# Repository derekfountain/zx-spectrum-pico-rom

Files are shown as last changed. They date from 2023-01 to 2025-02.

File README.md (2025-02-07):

# zx-spectrum-pico-rom

## A Pico-based switchable ROM interface for the ZX Spectrum

This is a ROM interface board for the ZX Spectrum. It presents a new,
selectable ROM image for the machine, replacing the 1982 BASIC one
found in the IC on the Spectrum's PCB.

There are lots of these around, all based on ROM and EEPROM chips. My
design is based on a Raspberry Pi Pico microcontroller programmed to
emulate a ROM chip.

The main advantage of doing it this way is that the Pico has enough
memory for several ROM images, and enough flash for as many ROMs as
anyone would likely ever want. A button allows the loaded ROMs to be
cycled.

It works like this (click through for YouTube video):

IMAGE ALT TEXT (http://www.youtube.com/watch?v=0Ot5mol2f5A "ZX ROM Interface")

https://youtube.com/shorts/0Ot5mol2f5A?feature=share

Update Dec'24: I used this Pico ROM project as the basis for a bit
of experimentation with the Z80's non maskable interrupt (NMI) on 
the Spectrum. Updated software and description are [here](https://github.com/derekfountain/zx-spectrum-pico-rom/tree/main/firmware_nmi).
If you're after a simpler version of the Pico code to do a simple
ROM emulation task, that's probably the version you want.

Update Feb'25: I further used this Pico ROM project as the basis for adding a carefully timed non maskable interrupt (NMI) which fires each frame at the point the Spectrum is about to draw the lower border. Not sure how much value there is there, but if anyone's interested the subproject is [here](https://github.com/derekfountain/zx-spectrum-pico-rom/tree/main/firmware_nmi_lower_border).

## Design

The Z80's address and data bus lines are connected to the Pico's
GPIOs.  GPIOs are limited on the Pico (there's only 26), so only 14 of
the 16 address lines are connected. A bit of external logic handles the
top two. The software on the Pico sits spinning, watching for that logic
to indicate that A14, A15 and /MREQ are all zero, that being the indication
of a ZX Spectrum ROM memory access by the Z80. When that condition is
met the address the Z80 is requesting (in the range 0x0000 to 0x3FFF)
is found from the GPIOs connected to the address bus, and the value from
that offset in the currently enabled ROM image is fetched. The 8 bits of
that value are placed on the 8 GPIOs connected as outputs to the Z80's
data bus.

## Hardware design

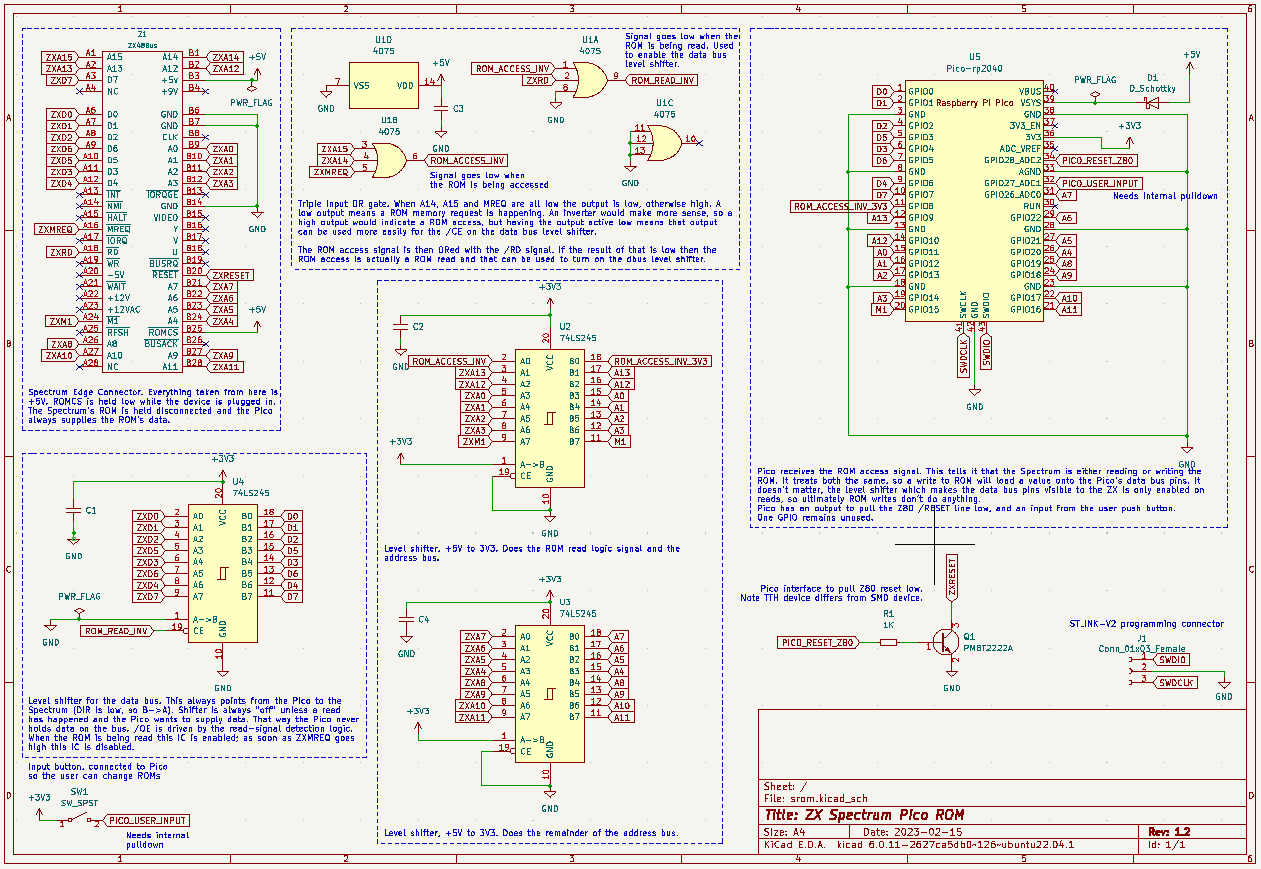
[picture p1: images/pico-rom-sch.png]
Pico ROM Schematic


The Spectrum is +5V, the Pico is 3V3, so every bus or signal pin needs
level shifting, down on the way into the Pico, up on the way out.

GPIO count is also pretty tight, which is why the external logic is
required. It's a simple 3-input OR gate which ORs A14, A15 and
/MREQ. The output of that gate is fed into the Pico, saving 2 GPIOs.

It's important that the device doesn't assert an output value onto the
Z80's data bus until it needs to. This is controlled by hardware. The
data bus level shifter is set permanently to the Pico->ZX direction,
but is left off (via its chip-enable line) until the ROM is being
read. The /CE line is pulled low by the output of the 3-way OR gate,
so when the Z80 is reading from ROM the level shifter is turned on and
the value on the data bus is connected to the Z80. As soon as the
/MREQ line goes high again the OR result goes true and the level shifter
is turned off again.

The Pico needs the ability to reset the Z80, which gets very unhappy if
the ROM program it's running is suddenly changed from underneath it. The
Z80's /RESET line is connected to a GPIO via a transistor; the line is
pulled low via Pico software when the Pico changes the ROM image in order
to reset the Z80.

There's a single user input button connected to the one remaining GPIO
on the Pico. In the current software this cycles the ROM to the next one
in the (compiled in) sequence. The Pico's ADC is available so more buttons
and a better user interface could be constructed using a resistor ladder.

The Z80's /M1 line is connected to a Pico GPIO input. This isn't required
for the typical use case, but it makes the device a useful test bed for
running the ZX Interface One ROM - see below.

### Caveat

Feb'25: I was playing around with one of these interfaces, and found myself
wanting to re-enable the Spectrum's ROM with the interface still plugged in.
(I needed the Pico for something, but with the Spectrum's own ROM.) So I
cut the /ROMCS track on the back of the interface, and then spent some time
trying to figure out why the Spectrum wasn't working.

Eventually it dawned on me: when I cut the track the Spectrum's ROM IC
was re-enabled, and it started to drive the data bus. But the U4 level
shifter was still working on the interface, which meant that was also driving
the data bus. That's a bad thing, the two ICs were both trying to be outputs
and were driving each other's data lines. The Z80 was getting garbage on the
data bus, and I think I was rather lucky nothing got damaged. I removed the
level shifter to complete my experimentation.

So, um, don't do that. :)

### Construction

The gerbers archive for upload, for example, JLCPCB, is
srom/fab1.2/fab1.2.zip. It's a simple 2 layer board.

Note: As of this writing I've not actually had one of these made. I
hand-modified my v1.1 board with the errata from v1.1. The v1.2 design
has had those modifications added so I'd expect it to work exactly the
same as my modified v1.1 board. But I haven't tried it yet. The switch,
in particular, might yet require another tweak depending on what
piece of hardware is chosen. I used a 6mm x 6mm right angle switch.

There's nothing complicated about the soldering. Do the big ICs first
and the Pico sockets, if you use them, last.

## Software Design

The software which runs on the Pico is built on a simple loop which
does this:

 * spin, waiting for the ROM-being-accessed signal to come in
 * read the 14 bits of the address bus from the GPIOs
 * convert that bit pattern into an offset
 * find the value of the byte at that offset into the currently
   used ROM image
 * apply the 8 bits of that byte value to the 8 output GPIOs connected
   to the Z80's data bus
 * go back to the top

The glaring issue here is speed. Pg8 of the Z80 manual says that the
timing for M1, the instruction fetch, is most time critical. The data
is sampled off the bus one and a half clocks after /MREQ goes low. On
the Spectrum's 3.5MHz Z80 that's 4.28571428571e-07 seconds, so about
430ns. Despite several efforts at optimisation I've been unable to get
the Pico to reliably return the data value inside that time frame. Much
to my frustration, v1.2 of the software still requires an overclock from
133MHz to 140MHz.

The Z80 starts up faster than the Pico which requires half a second or
so to get going. This means the Z80 is asking for ROM instructions 
before the Pico is ready to provide them. The Pico resets the Z80 as
soon as it, the Pico, is ready to go. That's why there's a colourful
display of randomness for a moment at startup.

## ROM Images

The device is permanently enabled; the original ROM chip in the
Spectrum is disabled while the interface is attached.

The Pico software contains the ROM images it's compiled with, the
first of which would typically be the original ZX ROM from 1982. I've
added a diagnostics ROM and the Gosh Wonderful ROM since they are free
to redistribute. Games ROMs are not included in the source release but
they can be added fairly easily. A Linux command like:

 xxd -i spaceraiders.rom

will convert a ROM image into 'C' array data which can be dropped into
roms.h.

### Switcher ROM

Some of the ROMs look superficially similar, like the original 1982
ROM and the Gosh Wonderful ROM. It got confusing trying to work out
what was running. I wanted a row of LEDs across the top of the device
to act as an indicator of which ROM was in use, but I didn't have any
GPIOs to implement it with. So I added an extra ROM image I called the
"switcher" ROM.

This program is written in 'C' and compiled with Z88DK. The source is
in the firmware/switcher directory. It presents a banner saying what ROM
is coming up next, then sits indefinitely buzzing the Spectrum's border.

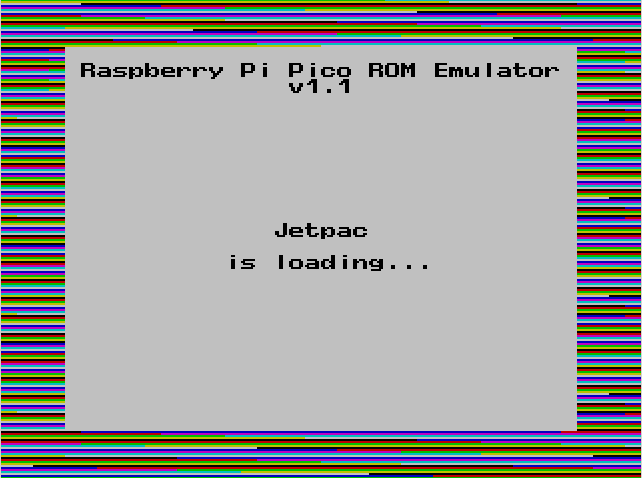
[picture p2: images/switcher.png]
Switcher ROM (under emulation)


When the user input button is pressed, the Pico software selects this
switcher ROM and resets the Z80 to start it running. The banner appears
on the Spectrum screen. About a second later an alarm goes off in the
Pico, the handler for which selects the next ROM in sequence and resets
the Z80 again. Thus the switcher ROM appears as a banner on the Spectrum
screen between each ROM switch.

## ZX Interface One

This device can also switch in and out the ZX Interface One's ROM. This
is an 8K ROM which, in the actual IF1, is paged in by hardware on 3 magic
address accesses: it's paged in when the Z80 requests an instruction from
addresses 0x0008 and 0x1708, and paged out again when the Z80 requests an
instruction from address 0x0700. It's early days with this idea, but that
boils down to this code:

    if( (rom_address == 0x0008) || (rom_address == 0x1708) )
    {
      rom_image_ptr = __ROMs_if1_rom;
    }
    else if( rom_address == 0x0700 )
    {
      rom_image_ptr = __ROMs_48_original_rom;
    }

This needs the /M1 input merged into the logic, but that's the
idea. The joys of programmable devices like the Pico, as opposed to
hardware. :)

There's a macro in the firmware source to switch in an early IF1 paging
version of the code. It seems unreliable, but I won't be persuing this
any further with this project.

Note: the v1.1 board doesn't have the /M1 signal connected. The v1.2
board has it connected into GPIO15. The software doesn't have the /M1
signal taken into account as yet.

## Bill of Materials

You will need:

3x [74LVC245 Bus transceiver](https://www.mouser.co.uk/ProductDetail/595-SN74LVC245ANSR)
Bus transceiver, used as a level shifter
<br>
1x [3216 SMD Diode](https://www.mouser.co.uk/ProductDetail/581-SD1206S040S2R0)
Schottky Diode for Pico input protection
<br>
1x [4075 OR gate](https://www.mouser.co.uk/ProductDetail/595-SN74HCS4075DR)
3-way 3-input OR gate
<br>
4x [3216 SMD 0.1uF capacitor](https://www.mouser.co.uk/ProductDetail/581-12065C104KAT4A)
Decoupling capacitor
<br>
1x [PMBT2222A SMD Transistor](https://www.mouser.co.uk/ProductDetail/771-PMBT2222A-T-R)
NPN Transistor for /RESET
<br>
1x [3216 SMD 1K Resistor](https://www.mouser.co.uk/ProductDetail/603-RT1206FRE071KL)
1K Resistor for /RESET

Also:

1x Raspberry Pi Pico with pins and sockets if you want them
<br>
1x ZX Spectrum Edge Connector socket
<br>
1x SPST switch any single pole, single throw switch to use as an input button. The footprint
on the board matches one I happen to have had, assume you'll add it on flying leads.

## Licence

Distributed as free software and hardware design under the GPL. The ROM
images have their own licences, see the ROMs/ directory.

Derek Fountain
February 2023

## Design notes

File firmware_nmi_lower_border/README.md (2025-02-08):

# zx-spectrum-lower-border-nmi

## A Pico-based NMI at the lower border point for the ZX Spectrum

I previously did some work looking at the use of the Z80's Non Maskable Interrupt with the ZX Spectrum. That work is [here](https://github.com/derekfountain/zx-spectrum-pico-rom/tree/main/firmware_nmi).

This sub-project builds on that idea, using RP2040 PIOs to generate a non maskable interrupt at a precisely defined point in the frame generation.

### Background

As most Spectrum aficionados know, the best time to redraw the screen and update sprites is when the border is being drawn. That way the screen won't flicker. Only, the Spectrum's hardware only has a single timer, which is the 50Hz signal the ULA emits when the video frame is about to be generated - i.e. when the raster beam is at the very top of the screen.

What might be useful, I thought, is a different interrupt which fires just as the ULA finishes drawing the screen data, which is the point it's just about to start drawing the lower border. Synching a program to that signal would give quite a bit more time to update the screen - the time needed to draw the lower border, plus the time needed to draw the top border.

This idea would require very precise timing, and the only reference point is the ULA's INT signal. The RP2040 on the Pico has its PIOs, which are very good at very precise signal handling. This project uses the PIOs to generate a NMI signal exactly as the ULA is about to start drawing the lower border.

### The Video Frame

A frame of the Spectrum's video signal looks like this on an oscilloscope (yellow trace shows the interrupt (INT) signal):

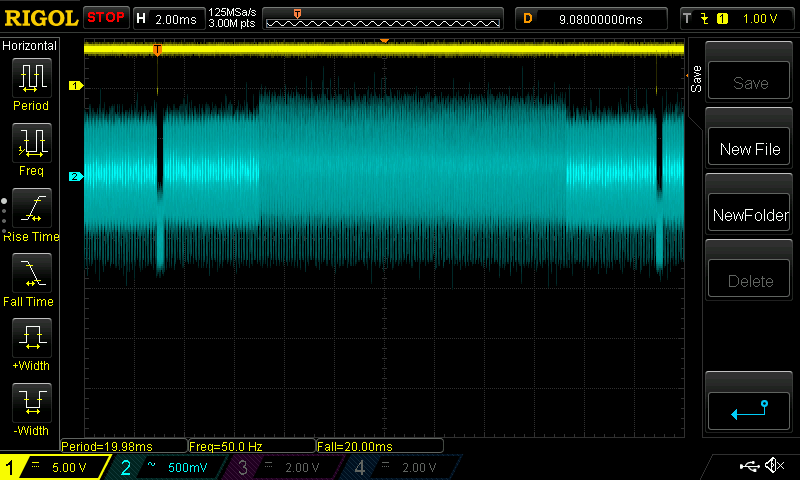
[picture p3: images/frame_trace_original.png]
Frame trace


There are 3 clearly defined areas of this signal, as annotated here:

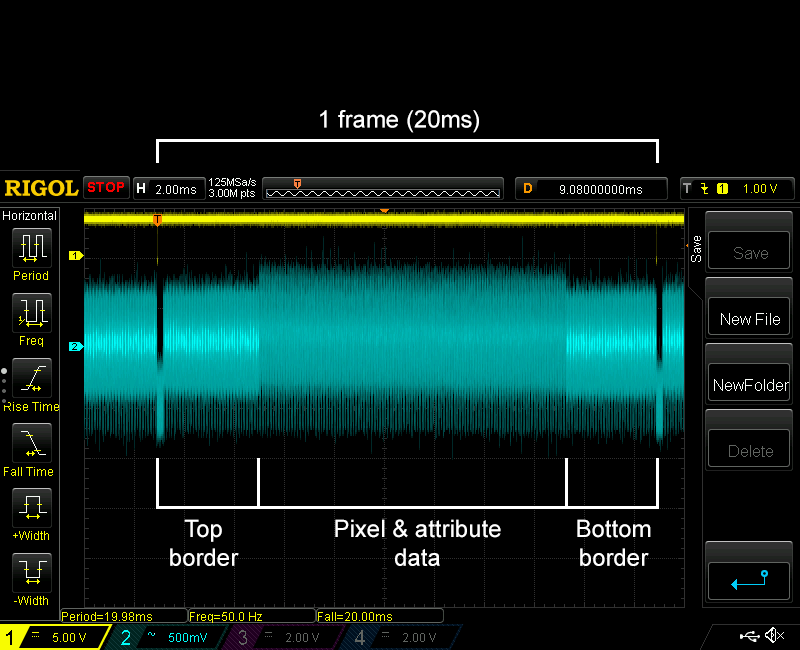
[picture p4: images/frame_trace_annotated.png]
Frame trace annotated


(Zooming in to the oscilloscpe trace shows the 192 lines of pixel data in that central block.)

The goal of this project is to generate a NMI signal at the exact point the bottom border is about to be drawn, as shown by the purple line here:

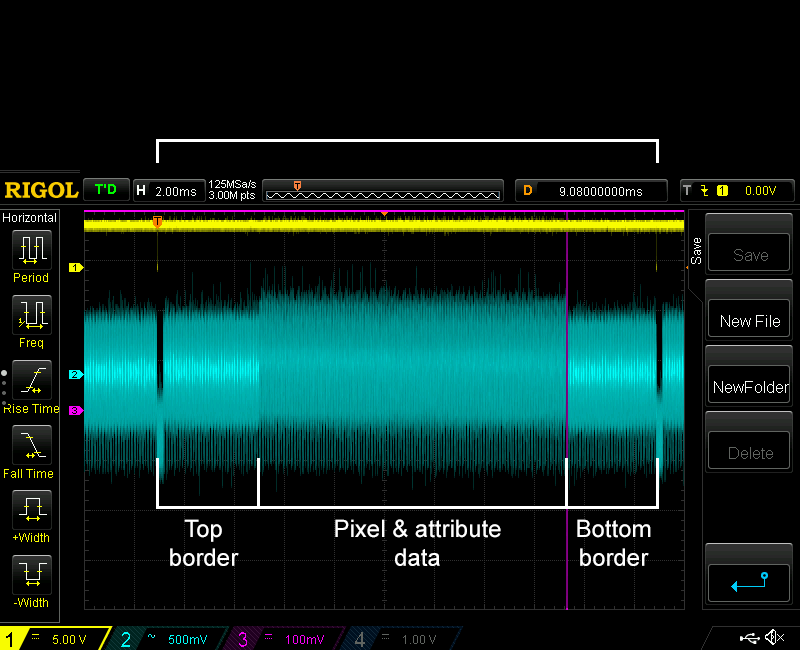
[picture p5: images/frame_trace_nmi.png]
Frame trace NMI


### The Result

The project works as designed, using a PIO-derived signal on each frame of video data (i.e. at 50Hz) to generate a non maskable interrupt on the Z80.

Look carefully at this photo of a Spectrum screen and you'll notice a thin, fractional, magenta line being drawn just underneath the lowest line of text:

Magenta line

That line is being drawn in the lower border by a NMI handler routine which just changes the border colour to magenta, then changes it back to white. The thin line thus created in the border is permanent, it just sits there. That includes when the Spectrum is running machine code programs with the interrupts disabled - it's a non maskable interrupt which is putting that line there.

This isn't a particularly useful example but it shows the NMI is being generated at exactly the right time, and the Z80 is running a simple handler for it.

## How it works

There are several pieces to this.

### ROM Emulator (modified)

The first is the piece of hardware which connects the Pico to the ZX Spectrum. For that I've used my ROM emulator project, which is the parent project of this one.

I modified it slightly, attaching the Z80's /INT signal to the Pico's GPIO 15. Ideally it would come in via a level shifter (5V to 3V3) but I didn't have a spare level shifter port. The RP2040 can handle a 5V input like this, so it's OK. The other modification is the NMI output signal from the RP2040 to the edge connector, and hence on to the Z80. I reused the original switch GPIO for this, that not being needed on this project.

So, just the two patch wires needed to modify the hardware.

### A PIO Program

The Spectrum's video takes exactly 20ms to draw, and hence runs at 50 frames per second. It's [312 scan lines high](https://worldofspectrum.org/faq/reference/48kreference.htm): 64 scans for the top border, 192 scans for the pixel data, then 56 scans for the lower border. Each scan line takes 224 T-states of the 3.5MHz Z80 to draw. Long story short, the NMI is required exactly 64+192 scan lines after the /INT signal is received. That's 64us, after which the /NMI signal to the Z80 needs to be pulled low.

The PIO program in this project does exactly that: wait for the /INT signal, then wait 64us, then pull the output GPIO low. The PIO program is this:

```
	 set pins, 1
 .wrap_target
	 wait 0 pin 0 [31]

     set x, 30 [31]
 first_lines:                                           
	 nop [31]
	 jmp x--, first_lines [31]

	 set pins, 0
	 set pins, 1
 .wrap
```

Start with the NMI output high, then wait for the /INT. There's a loop full of NOPs, then it toggles the output pin low and high. The numbers in square brackets are the delays on the PIO instructions, selected to set the timing exactly right. The lengthy comments in the PIO source code detail how the delays were worked out. I found it easier to reduce the clock speed of the PIO state machine from the 125MHz it normally runs at down to 125KHz. That made the correct delays much easier to generate.

### Spectrum ROM (modified)

When the Z80 receives the /NMI signal it jumps to location 0066h, which is in the Spectrum's ROM. The routine at that location isn't used, probably because it's buggy. But because I used my ROM emulator as the basis for this project, I'm in control of what's in the ROM, and I can fix the bug. In fact, what I actually did during development was put a single RETN instruction at location 0066h, which made testing predictable.

For the final version, which draws that magenta line, I put this in the ROM:

```
push af
ld a, 3
out (254),a
out (254),a
ld a, 7
out (254), a
pop af
retn
```

The original handler is 14 bytes, and that is 14 bytes, including the repeated 'out' instruction to set the border magenta. I had those 2 bytes spare, so I repeated the border colour change to make the magenta line a bit longer. Come to think of it, 2 NOPs would have done the job.

## Any Real Application?

This was mostly an exercise is trying to do something with non maskable interrupts on the Spectrum and PIOs on the RP2040. But it might have a real world application.

The Spectrum is a games machine, and I have in the past pondered hardware which would make for better games: smoother sprites, larger scrolled areas, etc. This would be a starting point, giving the games programmer a more reliable alternative to the [floating bus trick](http://sky.relative-path.com/zx/floating_bus.html), which aims to do the same thing from software.

In practise, um, no, not really, but if anyone has a use for it, feel free. :)

[Derek Fountain](https://www.derekfountain.org/zxspectrum.php), February 2025

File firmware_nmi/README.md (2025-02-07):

# zx-spectrum-nmi

## A Pico-based NMI testbed for the ZX Spectrum

I wanted to do some experimentation with the Z80's non maskable interrupt.
The Spectrum's NMI handler is buggy in the [Sinclair ROM](https://skoolkid.github.io/rom/dec/asm/102.html)
so it's never been possible to play with it, but with the ROM running from
an interface it's trivial to patch the problem in the interface's ROM image.

### Fixing the bug

The bug is simply a JR NZ instruction where a JR Z instruction was needed.
So my [ROM image](https://github.com/derekfountain/zx-spectrum-pico-rom/blob/9dbc9985f971bbe39fc13d4d96b5a7a9dd7bb2ee/firmware_nmi/roms.h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) needs a 0x28 in place of the 0x20, like this:

> 0xb5, 0x28, 0x01, 0xe9, 0xe1, 0xf1, 0xed, 0x45, 0x2a, 0x5d, 0x5c, 0x23,   /* <-- Fix at second byte here */

Simple.

### Modifying the interface

There's only one GPIO free on the board design, which is GPIO15. So I wired
that from the Pico to the NMI pin on the Spectrum's edge connector. This
gives the Pico the ability to trigger the Z80's NMI.

### Updating the interface code

The code running in the Pico needed a bit of tweaking. What it really needed
was simplfying, since for this project I didn't need any of the ROM switching
code I had in there.

The main issue I found was that the original code was designed to reset the
Spectrum after the switch is pressed. This project needs the Spectrum to keep
running after the switch is pressed, and it didn't. So that got restructured
a bit, then I found I had a timing problem.

The ROM emulation doesn't have much time to spare. It already had a slight
overclock on the RP2040 to make it reliable, and adding more code didn't help.
The code handles the Z80's read, then sits spinning while the Z80 finishes
what it's doing. Once that's complete and the read operation is done, there's
not much time until the next one starts.

It turned out the main culprit was the access to the realtime clock which was
used for the switch debounce logic. Reading that clock takes 1.5uS which is
quite a long time when you're trying to get stuff done between Z80 instructions.
So I changed the debounce algorithm and went to a 200MHz overclock. Not ideal,
but it works well enough.

## The Spectrum end

With the Spectrum's ROM bug fixed, the operation of the NMI is as follows.

You put an NMI handler in memory somewhere, then set the NMIADD (at 23728)
system variable to point to it. When the NMI line is pulled low the Z80 will
jump to address 0x0066 where the (fixed) handler will save AF and HL on the
stack, then jump to the address NMIADD points to.

So I put this little program in RAM at 0x8000:

```
ld a,3
out (254),a
ld a,7
out (254),a
pop hl
pop af
retn
```

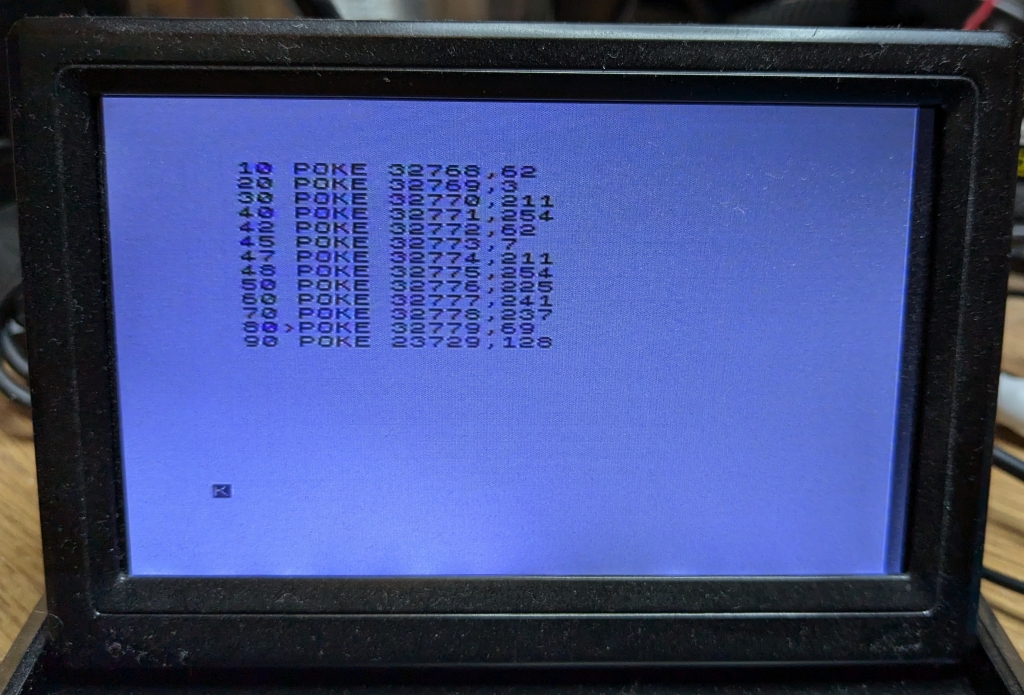
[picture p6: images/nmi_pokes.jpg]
POKEs to set up the NMI


So set the border to colour 3 (magenta) then set it back to colour 7 (white),
then restore the registers and return from the NMI. POKEing 23729 with 0x80
sets up NMIADD and ... it works! When I press the button on the interface
there's a quick flicker of magenta in the border.

I was quite pleased with getting that to work, but I can't really think what
to do with it.

Update Feb'25: I did a bit more with this NMI idea, using RP240 PIO to sync it to the 50Hz interrupt. Details [here](https://github.com/derekfountain/zx-spectrum-pico-rom/tree/main/firmware_nmi_lower_border).

[Derek Fountain](https://www.derekfountain.org/zxspectrum.php), December 2024

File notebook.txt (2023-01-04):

Project to get a Pico emulating a ROM on the Spectrum
=====================================================

Timing
======

Timing is based on a Z80 read, the ULA isn't involved. Pg8 of the Z80 manual says
that the timing for M1, the instruction fetch, is most time critical. The data is
sampled off the bus one and a half clocks after MREQ goes low. On the 3.5MHz Z80
that's 4.28571428571e-07 seconds. That's about 430ns.

For non-M1 accesses, timing is slower:

"Figure 6 shows the timing of memory read or write cycles other than an op code fetch
cycle. These cycles are generally three clock periods long unless wait states are requested
by memory through the WAIT signal."

The Interface2 doesn't use a WAIT signal, so the ROM needs to respond with data within the
expected timeframe, which is 3 clocks which is 8.57142857143e-07. That's 850ns.

430ns is therefore the requirement, and the Pico can do that quite easily.

This should be provable on a breadboard.

Signals
=======

The Interface 2 circuit is here:

http://www.fruitcake.plus.com/Sinclair/Interface2/Interface/Interface2_Circuitry.htm

It's got 16 address lines (inputs), 8 data lines (outputs) and the MREQ line (input).
It requires A14, A15 and MREQ to all go low to indicate a ROM (lower 16K) access.

The ROMCS (ROM Chip Select) line is permanently held high so the ZX ROM is permanently
disabled while the interface is plugged in.

The data bus GPIOs need to be left as inputs until a value is to be placed on them.
This is to allow other devices to use the Z80's data bus.

Pico Design
===========

Pico is GPIO constrained. It requires A0 to A15 as inputs, and D0 to D7 as outputs.
MREQ and RD will show that it's a memory access.

So I need 2 control lines, 16 address lines and 8 data lines. That's 26 lines. Bit
tight, but possible.

If /MREQ is low it's a memory access; if A14 and A15 are also low it's a memory
access of the lower 16K, the ROM. If the /RD line is also low it's a read of
the ROM, which is what I'm after. That's a 4 way OR, or maybe a 3 way OR plus
another 2 way OR. If I do this in discrete logic I'll free up some GPIOs.

I don't really want to have to have the Pico switching the output level shifter on.
It can do so, but it's another complication. So the design is to take the output
of the above described logic and use that to turn the level shifter on. When the
Z80 indicates it's doing a read from ROM, the active-low signal confirming that
can be used a /CE for the output level shifter.

I need to watch for a write to the ROM. In theory nothing will do that. I can use
it as a way for the Spectrum to communicate with the Pico. If I pass the output
of the discrete logic into the Pico it will be able to tell when ROM is being
accessed. If I pass in the /WR signal as well it will be able to tell if it's
being written to. This will allow POKE 0,?? to switch ROM. But that will crash
the Z80 so LD 0,???; JP 0 would be required. Unless the Pico can reset the Z80?
I don't think I have another level shifter port. Oh, maybe add a reset button
which yanks the RESET line, then the POKE and a manual press would do it?

Extra Ideas
===========

Probably need a timer circuit on /RESET to hold the Spectrum in reset until the
Pico has booted.

Need a way to get the Pico back to ROM0 (the Spectrum ROM). A power cycle will
do it, but a reset button might be useful.

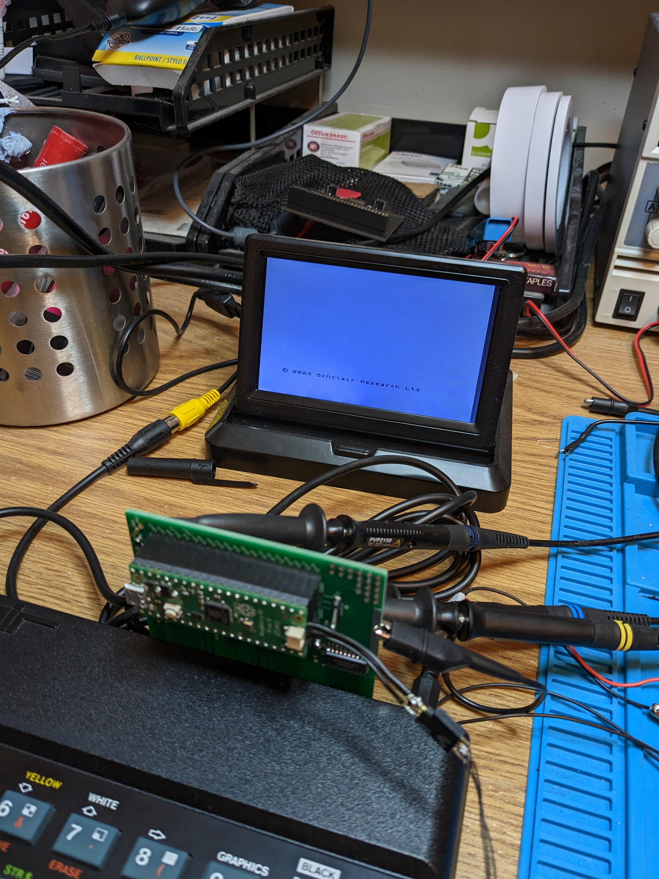
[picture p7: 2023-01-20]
srom/Images/first_working_version.jpg

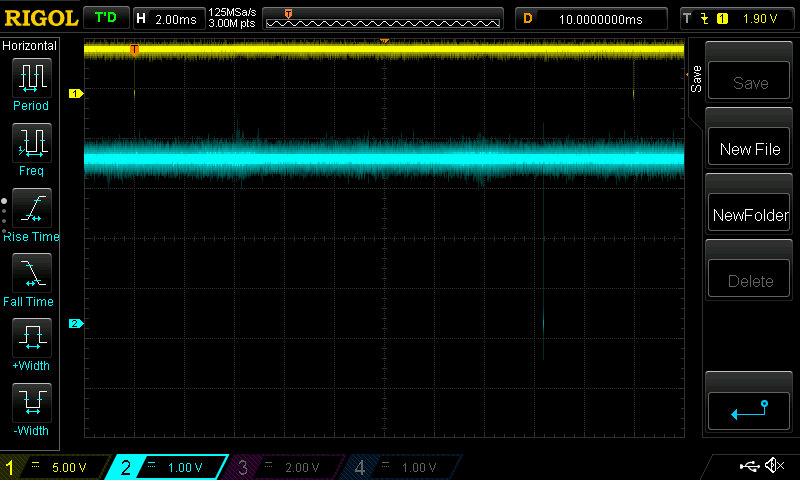
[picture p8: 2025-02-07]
images/nmi_from_int_pio.png

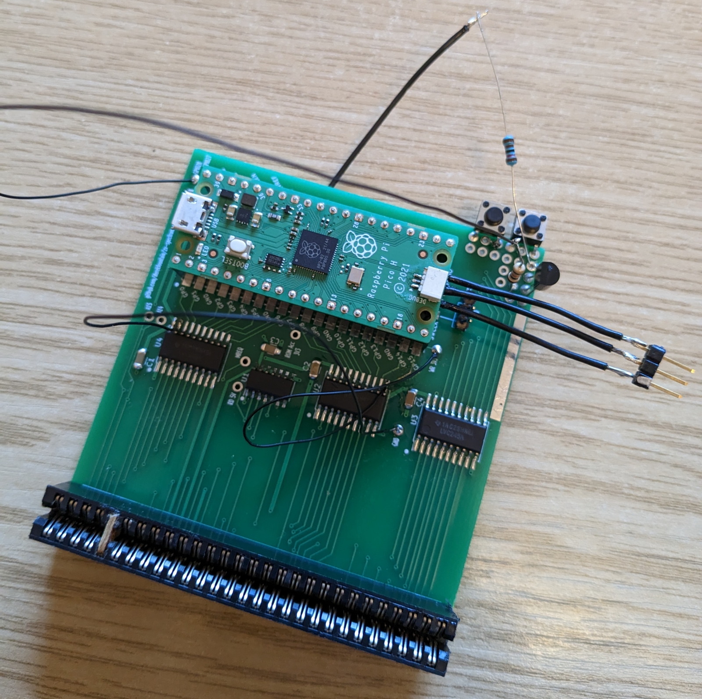
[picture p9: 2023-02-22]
images/first_version.jpg

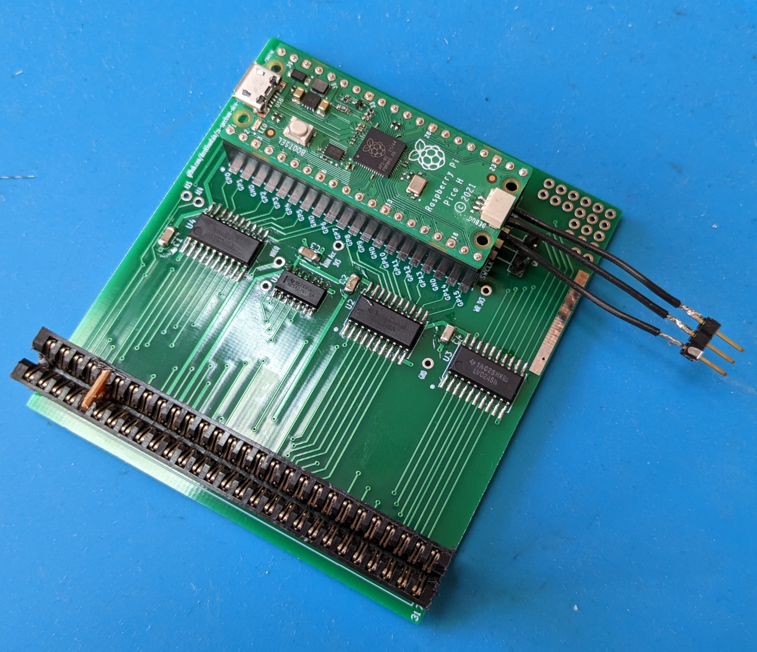
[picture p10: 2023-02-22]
images/first_built.jpg

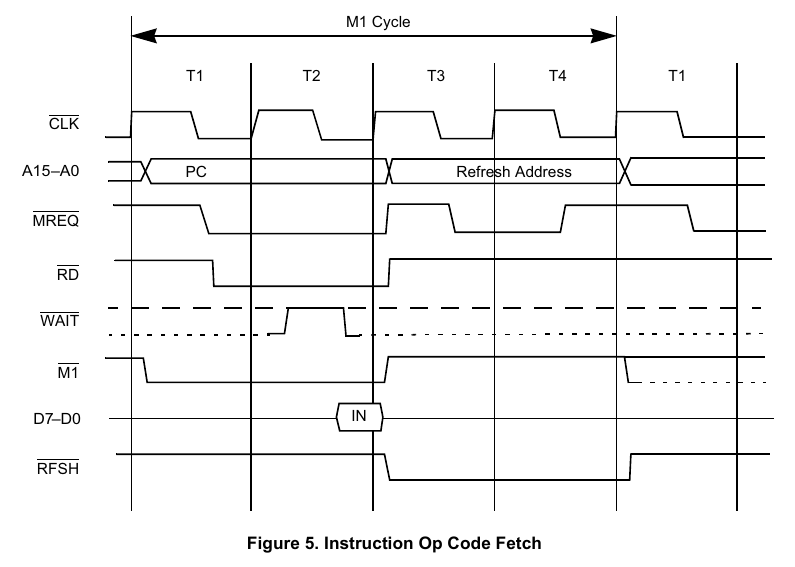
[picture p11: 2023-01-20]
srom/Images/mreq_timing_z80_datasheet.png

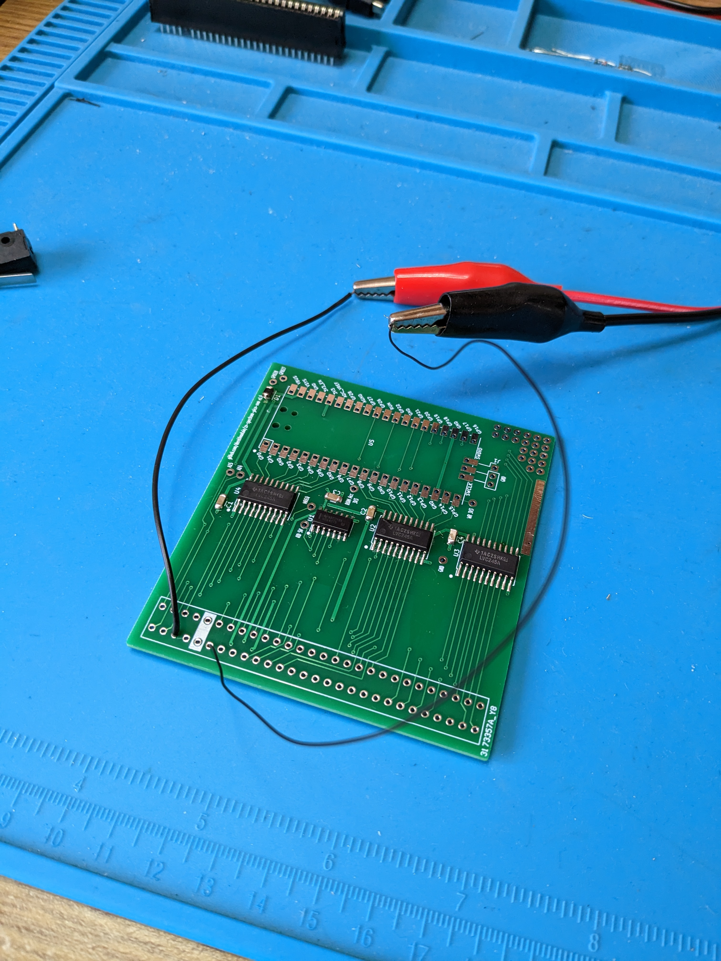
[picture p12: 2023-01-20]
srom/Images/initial_board.jpg

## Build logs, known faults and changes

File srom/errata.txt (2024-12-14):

1.0
===

The footprint for the SN74LVC245ANSR is wrong. The data sheet says 

SOIC (20) 12.80 mm × 7.50 mm

so I used the SOIC-20W_7.5x12.8mm_P1.27mm one. But there's a
discrepancy; the footprint is 7.5mm across the body of the device,
the datasheet says that distance is across the pins. The body of
the device is 5.00mm to 5.6mm according to the datasheet (which
it is). There isn't a non-wide version of that footprint in the
KiCAD libs. The one to use appears to be the SO-20_5.3x12.6mm_P1.27mm
one.

The footprint for the Pico's schottky diode is wrong. I copied AM's
circuit where he's used a SOD323 footprint. The diodes I bought are
3216 sized, and so too big. Increase footprint size.

I don't need the /WR line at the Pico. The level shifter for the
data bus is permanently in the Pico->ZX direction, so I can't
pick up a written value from the data bus. That level shifter is
turned on/off by hardware so there's no issue with the device
responding to a write-to-ROM in the same way as it responds to
a read-from-ROM. Delete the /WR connection and reclaim the GPIO
on the Pico.

It needs access to the Z80's /RESET line. It's a pain having to
use the switch on the Spectrum for something that the board can
do itself. This is also needed to start at address 0 when a new
ROM gets switched in. Pico needs a GPIO set to output which it
can use to bring the Z80's /RESET line low. I can use the GPIO
freed by the now unneeded /WR connection.

It needs a user input button. Writing to the ROM to reboot doesn't
seem practical. Pressing the button can advance to the next ROM in
the build. I think a brief press will select the next ROM and reset
the Z80, a long press can reboot the Pico itself.

In order for the Interface One ROM to page at the correct time I
need the Z80's /M1 signal. It's sort of a side point for the
purpose of this device, but will be useful for testing as I start
the IF1 project. I have a spare level shift and GPIO on the Pico.

I need +5V and 3V3 test points.

v1.1
====

The footprint for the right angle 6x6mm switch is wrong.
Button_Switch_THT:SW_Tactile_SKHH_Angled looks like a better option.
Fixed for v1.2.

The NPN2222 SMD transistor has a different pinout to the TTH hole I
used for prototyping. I created a new symbol with correct footprint
for v1.2.

The Pico receives a signal called ROM_ACCESS_INV, which is A14, A15
and /MREQ ORed together. Unfortunately that logic allows memory
refreshes through - see the Instruction Fetch section of the Z80
manual. This made sense when the Pico had the /RD signal, but since
that's now gone the Pico can't tell a read, write or refresh.
That's bad for the Interface One paging mechanism which
must only page with a memory read; a memory refresh of 0x0008 happens
at Z80 startup. The solution appears to be to put the ROM_READ_INV
signal through the level shifter and into the Pico instead of
ROM_ACCESS_INV, but I haven't done it yet. Needs thinking through.
For the IF1-demo use case /M1 can be used instead. /M1 goes high
for the refresh part of the read so the Pico can see the page
isn't required at that point. But see next point.

The 1.1 boards were fabricated with the Pico's GP15 not connected to
anything. It was /WR, which I disconnected. I intended to connect
/M1 but didn't actually do so. If this board is to run the IF1 ROM
switching reliably the /M1 signal will have to be put through the
level shifter and into the Pico. PCB has been updated with this
change for v1.2.

v1.2
====

The switch (SW1) casing isn't connected to ground. This makes it
susceptible to ESD: when I touch the switch's metal casing the
Spectrum sometimes crashes or reset. I think the issue is capacitive
coupling. Static from my fingertip goes through the capacitor formed
by the switch casing on one side and the Pico/ZX circuit on the
other, and the voltage ends up somewhere it shouldn't, like the Z80.
I soldered a wire from the switch case to a ground point and that
solved the issue.
Fixed for v1.3. I set the switch anchor points to GND net.

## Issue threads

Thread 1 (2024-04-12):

suggestion to retarget tje board

aldolo69, 2024-04-12:
hi. don't know how to write to you in another way.
in your opinion is possible to build a .z80 loader? for the porpuse maybe only 512bytes of the initial rom could be enough so you can freeup some pins for the sd card and buttons. you can makup the rom in chunks of LD command to fill the RAM and then release the z80 and the original ROM. i'm too lazy to start such a project now... seems doable.

derekfountain, 2024-04-14:
I think the approach could be made to work with enough effort. The issue, as ever with the Pico, is the number of GPIOs available.

If you re-purposed the GPIO which currently connects the /M1 line (as part of the IF1 experimentation I was doing), you could emulate a 1024b ROM with 4 GPIOs free. Those GPIOs could drive an SD card reader (MISI, MISO, CLK and SLAVE_ENABLE), the contents of which could be moved into Spectrum RAM in chunks as you suggest.

Hmmm, but then when your game is loaded and started you wouldn't have the original ROM in place, and that code is used by lots of games. So you'd need the ability to turn the device off which you could do by driving /ROMCS, but that would need another GPIO. You could re-purpose another address line and go down to a 512b ROM, which would probably still be enough for the Z80 program. So I think that bit would work. You wouldn't have any free GPIOs for user interface buttons though.

To be honest, if I were going to design such a project, I'm not sure I'd start with this one!

derekfountain, 2024-12-15:
Nothing further planned on this.

Closed 2024-12-15.

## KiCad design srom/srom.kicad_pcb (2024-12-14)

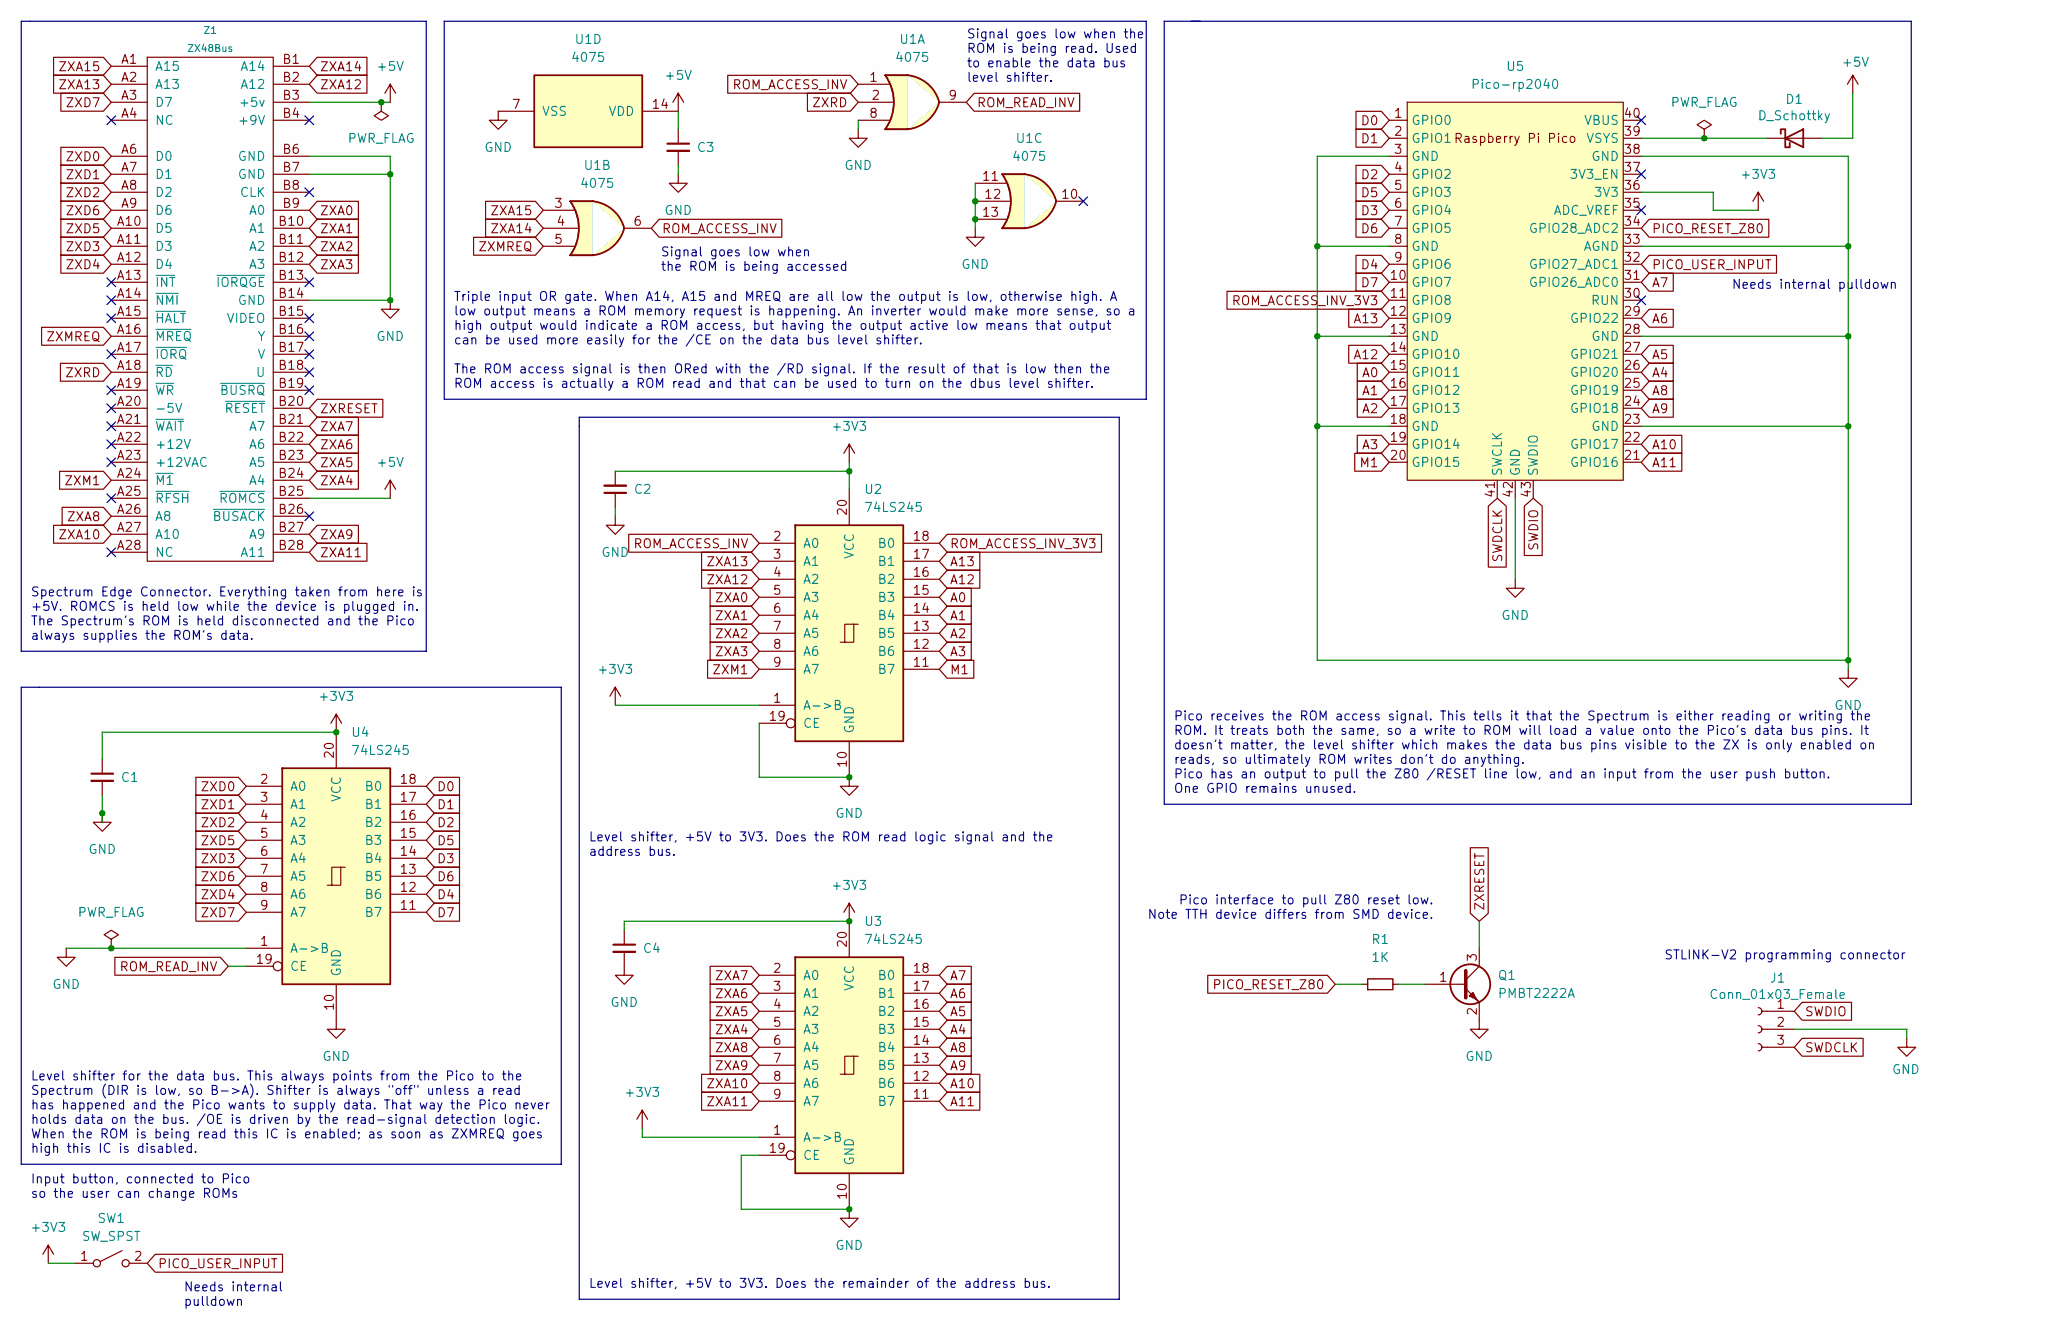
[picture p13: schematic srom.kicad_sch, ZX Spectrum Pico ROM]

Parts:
C1, C2, C3, C4: C_Small; C_1206_3216Metric
D1: D_Schottky; D_1206_3216Metric_Pad1.42x1.75mm_HandSolder
J1: Conn_01x03_Female; PinHeader_1x03_P2.54mm_Vertical
Q1: PMBT2222A; TSOT-23_HandSoldering
R1: 1K; R_1206_3216Metric_Pad1.30x1.75mm_HandSolder
SW1: SW_SPST; SW_Tactile_SKHH_Angled
U1: 4075; SOIC-14_3.9x8.7mm_P1.27mm
U2, U3, U4: 74LS245; SO-20_5.3x12.6mm_P1.27mm
U5: Pico-rp2040; RPi_Pico_SMD_TH
Z1: ZX48Bus; ZX_Bus_Pin_Header

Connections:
+3V3: C1.1, C2.2, C4.1, SW1.1 (A), U2.1 (A->B), U2.20 (VCC), U3.1 (A->B), U3.20 (VCC), U4.20 (VCC), U5.36 (3V3)
+5V: C3.1, D1.2 (A), U1.14 (VDD), Z1.B3 (+5v), Z1.B25 (~ROMCS)
A0: U2.15 (B3), U5.15 (GPIO11)
A1: U2.14 (B4), U5.16 (GPIO12)
A2: U2.13 (B5), U5.17 (GPIO13)
A3: U2.12 (B6), U5.19 (GPIO14)
A4: U3.15 (B3), U5.26 (GPIO20)
A5: U3.16 (B2), U5.27 (GPIO21)
A6: U3.17 (B1), U5.29 (GPIO22)
A7: U3.18 (B0), U5.31 (GPIO26_ADC0)
A8: U3.14 (B4), U5.25 (GPIO19)
A9: U3.13 (B5), U5.24 (GPIO18)
A10: U3.12 (B6), U5.22 (GPIO17)
A11: U3.11 (B7), U5.21 (GPIO16)
A12: U2.16 (B2), U5.14 (GPIO10)
A13: U2.17 (B1), U5.12 (GPIO9)
D0: U4.18 (B0), U5.1 (GPIO0)
D1: U4.17 (B1), U5.2 (GPIO1)
D2: U4.16 (B2), U5.4 (GPIO2)
D3: U4.14 (B4), U5.6 (GPIO4)
D4: U4.12 (B6), U5.9 (GPIO6)
D5: U4.15 (B3), U5.5 (GPIO3)
D6: U4.13 (B5), U5.7 (GPIO5)
D7: U4.11 (B7), U5.10 (GPIO7)
GND: C1.2, C2.1, C3.2, C4.2, J1.2, Q1.2 (E), U1.7 (VSS), U1.8, U1.11, U1.12, U1.13, U2.10 (GND), U2.19 (CE), U3.10 (GND), U3.19 (CE), U4.1 (A->B), U4.10 (GND), U5.3 (GND), U5.8 (GND), U5.13 (GND), U5.18 (GND), U5.23 (GND), U5.28 (GND), U5.33 (AGND), U5.38 (GND), U5.42 (GND), Z1.B6 (GND), Z1.B7 (GND), Z1.B14 (GND)
M1: U2.11 (B7), U5.20 (GPIO15)
unnamed: D1.1 (K), U5.39 (VSYS)
unnamed: Q1.1 (B), R1.2
PICO_RESET_Z80: R1.1, U5.34 (GPIO28_ADC2)
PICO_USER_INPUT: SW1.2 (B), U5.32 (GPIO27_ADC1)
ROM_ACCESS_INV: U1.1, U1.6, U2.2 (A0)
ROM_ACCESS_INV_3V3: U2.18 (B0), U5.11 (GPIO8)
ROM_READ_INV: U1.9, U4.19 (CE)
SWDCLK: J1.3, U5.41 (SWCLK)
SWDIO: J1.1, U5.43 (SWDIO)
ZXA0: U2.5 (A3), Z1.B9 (A0)
ZXA1: U2.6 (A4), Z1.B10 (A1)
ZXA2: U2.7 (A5), Z1.B11 (A2)
ZXA3: U2.8 (A6), Z1.B12 (A3)
ZXA4: U3.5 (A3), Z1.B24 (A4)
ZXA5: U3.4 (A2), Z1.B23 (A5)
ZXA6: U3.3 (A1), Z1.B22 (A6)
ZXA7: U3.2 (A0), Z1.B21 (A7)
ZXA8: U3.6 (A4), Z1.A26 (A8)
ZXA9: U3.7 (A5), Z1.B27 (A9)
ZXA10: U3.8 (A6), Z1.A27 (A10)
ZXA11: U3.9 (A7), Z1.B28 (A11)
ZXA12: U2.4 (A2), Z1.B2 (A12)
ZXA13: U2.3 (A1), Z1.A2 (A13)
ZXA14: U1.4, Z1.B1 (A14)
ZXA15: U1.3, Z1.A1 (A15)
ZXD0: U4.2 (A0), Z1.A6 (D0)
ZXD1: U4.3 (A1), Z1.A7 (D1)
ZXD2: U4.4 (A2), Z1.A8 (D2)
ZXD3: U4.6 (A4), Z1.A11 (D3)
ZXD4: U4.8 (A6), Z1.A12 (D4)
ZXD5: U4.5 (A3), Z1.A10 (D5)
ZXD6: U4.7 (A5), Z1.A9 (D6)
ZXD7: U4.9 (A7), Z1.A3 (D7)
ZXM1: U2.9 (A7), Z1.A24 (~M1)
ZXMREQ: U1.5, Z1.A16 (~MREQ)
ZXRD: U1.2, Z1.A18 (~RD)
ZXRESET: Q1.3 (C), Z1.B20 (~RESET)

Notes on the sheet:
Needs internal pulldown
Level shifter, +5V to 3V3. Does the remainder of the address bus.
Level shifter, +5V to 3V3. Does the ROM read logic signal and the address bus.
Pico receives the ROM access signal. This tells it that the Spectrum is either reading or writing the ROM. It treats both the same, so a write to ROM will load a value onto the Pico's data bus pins. It doesn't matter, the level shifter which makes the data bus pins visible to the ZX is only enabled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
Needs internal pulldown
Level shifter for the data bus. This always points from the Pico to the Spectrum (DIR is low, so B->A). Shifter is always "off" unless a read has happened and the Pico wants to supply data. That way the Pico never holds data on the bus. /OE is driven by the read-signal detection logic. When the ROM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
Triple input OR gate. When A14, A15 and MREQ are all low the output is low, otherwise high. A low output means a ROM memory request is happening. An inverter would make more sense, so a high output would indicate a ROM access, but having the output active low means that output can be used more easi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
Pico interface to pull Z80 reset low. Note TTH device differs from SMD device.
Signal goes low when the ROM is being read. Used to enable the data bus level shifter.
Spectrum Edge Connector. Everything taken from here is +5V. ROMCS is held low while the device is plugged in. The Spectrum's ROM is held disconnected and the Pico always supplies the ROM's data.
Input button, connected to Pico so the user can change ROMs
Signal goes low when the ROM is being accessed
STLINK-V2 programming connector

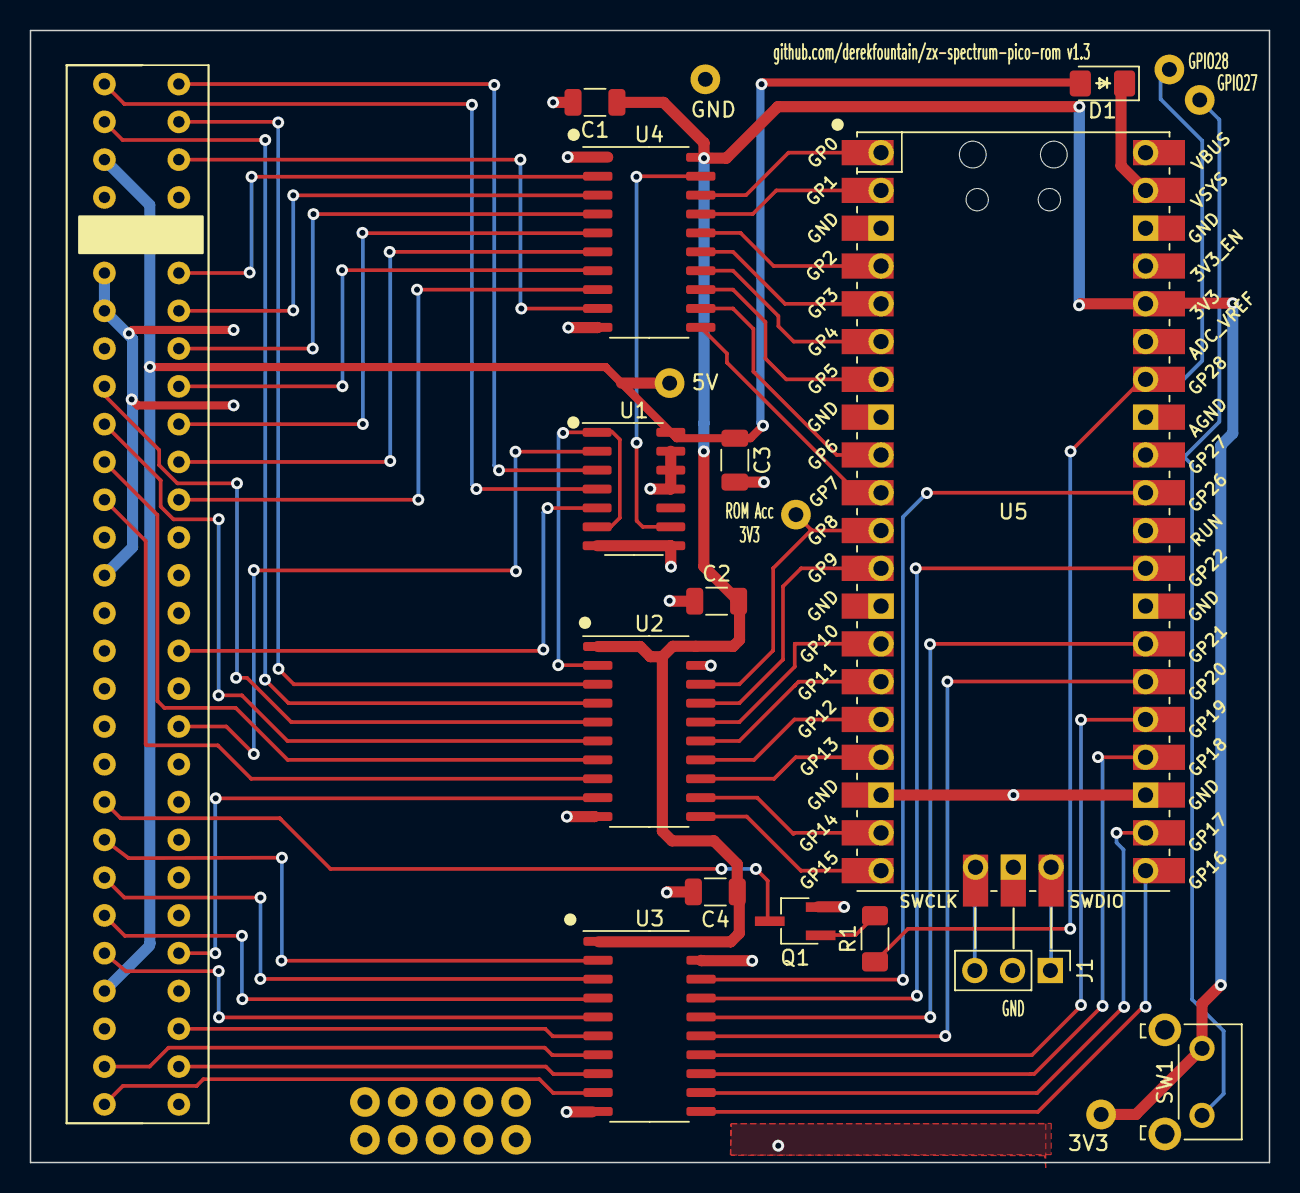
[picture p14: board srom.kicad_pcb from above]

Board: 2 copper layers, 83.3 x 76.1 mm, 27 parts (0 on the bottom side), 63 nets.

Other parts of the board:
5, 6, 7, 8, 9, 10, 11, 12, 13, 14, 14#2, 14#3: (no value)

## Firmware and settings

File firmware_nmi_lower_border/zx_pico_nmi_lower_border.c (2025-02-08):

/*
 * ZX Pico Lower Border Experimentation Firmware, a Raspberry Pi Pico
 * based ZX Spectrum research project
 * Copyright (C) 2025 Derek Fountain
 * 
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
 * You should have received a copy of the GNU General Public License
 * along with this program; if not, write to the Free Software
 * Foundation, Inc., 51 Franklin Street, Fifth Floor, Boston, MA  02110-1301, USA.
 */

/*
 * cmake -DCMAKE_BUILD_TYPE=Debug ..
 * make -j10
 * sudo openocd -f interface/picoprobe.cfg -f target/rp2040.cfg -c "program ./zx_pico_nmi_lower_border.elf verify reset exit"
 * sudo openocd -f interface/picoprobe.cfg -f target/rp2040.cfg
 * gdb-multiarch zx_pico_nmi_lower_border.elf
 *  target remote localhost:3333
 *  load
 *  monitor reset init
 *  continue
 */

#include <stdio.h>
#include <stdint.h>
#include <string.h>
#include <stdlib.h>
#include "pico/stdlib.h"
#include "pico/multicore.h"
#include "hardware/gpio.h"
#include "pico/binary_info.h"
#include "hardware/timer.h"

#include "lower_border_timer.pio.h"

/* 1 instruction on the 133MHz microprocessor is 7.5ns */
/* 1 instruction on the 140MHz microprocessor is 7.1ns */
/* 1 instruction on the 150MHz microprocessor is 6.6ns */
/* 1 instruction on the 200MHz microprocessor is 5.0ns */

#if 1
/*
 * The ROM emulation needs a slight overclock because it has to unjumble
 * the data bus GPIOs lines. A design mistake I won't make again.
 * My PIO calculations assume the Pico's native 125MHz clock, which
 * I divide by 1,000, so this keeps it precise.
 */
#define OVERCLOCK_KHZ 150000
#define PIO_DIVIDER ((OVERCLOCK_KHZ/125000.0)*1000.0)
#endif

#include "roms.h"

const uint8_t LED_PIN = PICO_DEFAULT_LED_PIN;

/*
 * These pin values are the GPxx ones in green background on the pinout diagram.
 * See schematic for how the signals are fed into the Pico's GPIOs
 */
const uint8_t A0_GP          = 11;
const uint8_t A1_GP          = 12;
const uint8_t A2_GP          = 13;
const uint8_t A3_GP          = 14;
const uint8_t A4_GP          = 20;
const uint8_t A5_GP          = 21;
const uint8_t A6_GP          = 22;
const uint8_t A7_GP          = 26;
const uint8_t A8_GP          = 19;
const uint8_t A9_GP          = 18;
const uint8_t A10_GP         = 17;
const uint8_t A11_GP         = 16;
const uint8_t A12_GP         = 10;
const uint8_t A13_GP         = 9;

/*
 * Given the GPIOs with an address bus value on them, this packs the
 * 14 address bits down into the least significant 14 bits
 */
inline uint16_t pack_address_gpios( uint32_t gpios )
{
  /*     Bits 0,1,2,3,4,5       Bits 6,7,8,9,10,11,12     Bit 13                   */
  return ((gpios>>9) & 0x03F) | ((gpios>>10) & 0x1FC0) | ((gpios & 0x4000000) >> 13);
}

/*
 * Given value i, this calculates the pattern of the GPIOs if
 * value i were to appear on the Z80 address bus.
 */
uint32_t create_gpios_for_address( uint32_t i )
{
  uint32_t gpio_pattern = 
    ( ((i & 0x0001) >>  0) <<  A0_GP ) |
    ( ((i & 0x0002) >>  1) <<  A1_GP ) |
    ( ((i & 0x0004) >>  2) <<  A2_GP ) |
    ( ((i & 0x0008) >>  3) <<  A3_GP ) |
    ( ((i & 0x0010) >>  4) <<  A4_GP ) |
    ( ((i & 0x0020) >>  5) <<  A5_GP ) |
    ( ((i & 0x0040) >>  6) <<  A6_GP ) |
    ( ((i & 0x0080) >>  7) <<  A7_GP ) |
    ( ((i & 0x0100) >>  8) <<  A8_GP ) |
    ( ((i & 0x0200) >>  9) <<  A9_GP ) |
    ( ((i & 0x0400) >> 10) << A10_GP ) |
    ( ((i & 0x0800) >> 11) << A11_GP ) |
    ( ((i & 0x1000) >> 12) << A12_GP ) |
    ( ((i & 0x2000) >> 13) << A13_GP );

  return gpio_pattern;
}


const uint8_t  D0_GP          = 0;
const uint8_t  D1_GP          = 1;
const uint8_t  D2_GP          = 2;
const uint8_t  D3_GP          = 4; 
const uint8_t  D4_GP          = 6;
const uint8_t  D5_GP          = 3;
const uint8_t  D6_GP          = 5;
const uint8_t  D7_GP          = 7;

const uint32_t  D0_BIT_MASK  = ((uint32_t)1 <<  D0_GP);
const uint32_t  D1_BIT_MASK  = ((uint32_t)1 <<  D1_GP);
const uint32_t  D2_BIT_MASK  = ((uint32_t)1 <<  D2_GP);
const uint32_t  D3_BIT_MASK  = ((uint32_t)1 <<  D3_GP);
const uint32_t  D4_BIT_MASK  = ((uint32_t)1 <<  D4_GP);
const uint32_t  D5_BIT_MASK  = ((uint32_t)1 <<  D5_GP);
const uint32_t  D6_BIT_MASK  = ((uint32_t)1 <<  D6_GP);
const uint32_t  D7_BIT_MASK  = ((uint32_t)1 <<  D7_GP);

const uint8_t  ROM_ACCESS_GP            = 8;
const uint32_t ROM_ACCESS_BIT_MASK      = ((uint32_t)1 << ROM_ACCESS_GP);

/* This pin triggers a transistor which shorts the Z80's /RESET to ground */
const uint8_t  PICO_RESET_Z80_GP        = 28;

/* NMI output to Spectrum */
const uint8_t  NMI_GP                   = 27;

/* INT input from the Spectrum */
const uint8_t  INT_GP                   = 15;

const uint32_t DBUS_MASK     = ((uint32_t)1 << D0_GP) |
                               ((uint32_t)1 << D1_GP) |
                               ((uint32_t)1 << D2_GP) |
                               ((uint32_t)1 << D3_GP) |
                               ((uint32_t)1 << D4_GP) |
                               ((uint32_t)1 << D5_GP) |
                               ((uint32_t)1 << D6_GP) |
                               ((uint32_t)1 << D7_GP);

/*
 * The 14 address bus bits arrive on the GPIOs in a weird pattern which is
 * defined by the edge connector layout and the board design. Shifting all
 * 14 bits into place works, but it's slow, it needs all 14 masks and shifts
 * done each byte read from ROM. The Pico needs a significant overclock to
 * manage that.
 *
 * This is an optimisation. Take the 14 address bus bits, which are scattered
 * in the 32bit GPIO value, and shift them down into the lowest 14 bits of
 * a 16 bit word. They're not in order A0 to A13, they're in some weird order.
 * So this is a conversion table. The index into this is the weird 14 bit
 * value, the value at that offset into this table is the actual address bus
 * value the weird value represents.
 *
 * e.g. you might read the GPIOs, shuffle the 14 bits down and end with,
 * say, 0x032A. Look up entry 0x032A in this table and find, say, 0x0001.
 * That means when 0x32A appears on the mixed up address bus, the actual
 * address bus value the Z80 has passed in is 0x0001. It wants that byte
 * from the ROM.
 *
 * This table is filled in at the start; a lookup is done here for each
 * ROM byte read.
 */
uint16_t address_indirection_table[ 16384 ];


/*
 * The bits of the bytes in the ROM need shuffling around to match the
 * ordering of the D0-D7 bits on the output GPIOs. See the schematic.
 * Do this now so the pre-converted bytes can be put straight onto
 * the GPIOs at runtime.
 */
void preconvert_rom( uint8_t *image_ptr, uint32_t length )
{
  uint16_t conv_index;
  for( conv_index=0; conv_index < length; conv_index++ )
  {
    uint8_t rom_byte = *(image_ptr+conv_index);
    *(image_ptr+conv_index) =  (rom_byte & 0x87)       |        /* bxxx xbbb */
                              ((rom_byte & 0x08) << 1) |        /* xxxb xxxx */
                              ((rom_byte & 0x10) << 2) |        /* xbxx xxxx */
                              ((rom_byte & 0x20) >> 2) |        /* xxxx bxxx */
                              ((rom_byte & 0x40) >> 1);         /* xxbx xxxx */
  }
}


/*
 * Populate the address bus indirection table.
 */
void create_indirection_table( void )
{
  uint32_t i;

  /*
   * Loop over all 16384 address the Z80 might ask for. For each one calculate
   * the pattern of the GPIOs when that value is on the address bus. Then pack
   * that pattern down into the lowest 14 bits. That's the value which is
   * found for each read byte, so the value at that offset into the table is
   * the original value which will match what the Z80's after.
   */
  for( i=0; i<16384; i++ )
  {
    uint32_t raw_bit_pattern = create_gpios_for_address( i );

    uint32_t packed_bit_pattern = pack_address_gpios( raw_bit_pattern );

    address_indirection_table[packed_bit_pattern] = i;
  }

  return;
}


/* Just the one ROM image for this version */
const uint8_t *rom_image_ptr = __ROMs_48_original_rom;

#define USE_PIO 1
#if USE_PIO
/*
 * This is called by an alarm function.
 */
int64_t start_nmi_pulsing_func_pio( alarm_id_t id, void *user_data )
{
  int timer_sm;
  PIO timer_pio = pio1;
  uint timer_offset;

  gpio_set_function(INT_GP, GPIO_FUNC_PIO1);    
  gpio_set_function(NMI_GP, GPIO_FUNC_PIO1);    

  /* Set up the PIO state machine */
  timer_sm        = pio_claim_unused_sm(timer_pio, true);
  timer_offset    = pio_add_program(timer_pio, &lower_border_timer_program);
  lower_border_timer_program_init(timer_pio, timer_sm, timer_offset, INT_GP, NMI_GP);

  /* Set the clock divider to get a more manageable frequency (must be done after initialisation) */
  pio_sm_set_clkdiv(timer_pio, timer_sm, PIO_DIVIDER);

  /* Set it running */
  pio_sm_set_enabled(timer_pio, timer_sm, true);

  gpio_put(LED_PIN, 1);

  /* Timers have done their job, all interrupts off now */
  irq_set_mask_enabled( 0xFFFFFFFF, 0 );

  return 0;
}
#else
int64_t start_nmi_pulsing_func( alarm_id_t id, void *user_data )
{
  gpio_put( NMI_GP, 0 );
  busy_wait_us_32(10);     /* Shows on scope, could be faster */
  gpio_put( NMI_GP, 1 );

  /*
   * In theory this is 20ms, but not synced to /INT. In practice
   * the gpio_put()s and other bits slow it down and the timing
   * isn't quite right. So the PIO solution is still needed.
   */
  return 2000000;
}
#endif

/*
 * This is called by an alarm function. It lets the Z80 run by pulling the
 * Pico's controlling GPIO low
 */
int64_t start_z80_alarm_func( alarm_id_t id, void *user_data )
{
  gpio_put( PICO_RESET_Z80_GP, 0 );

  return 0;
}

/*
 * ROM emulation runs on the other core. It's time critical, so
 * this core handles everything else
 */
void core1_main( void )
{
  /* All interrupts off on this core except the timers */
  irq_set_mask_enabled( 0xFFFFFFFF, 0 );
  irq_set_mask_enabled( 0x0000000F, 1 );

  /*
   * Ready to go, give it a millisecond for this Pico code to get into
   * its main loop, then let the Z80 start
   */
  add_alarm_in_ms( 1, start_z80_alarm_func, NULL, 0 );

  /* Start with NMI high (inactive) */
  gpio_init( NMI_GP );  gpio_set_dir( NMI_GP, GPIO_OUT );
  gpio_put( NMI_GP, 1 );

  /* When everything is running, start the NMI pulsing */
  add_alarm_in_ms( 2, start_nmi_pulsing_func_pio, NULL, 0 );

  while(1)
    sleep_ms(1);
}

int main()
{
  bi_decl(bi_program_description("ZX Spectrum Pico NMI lower border binary."));

#ifdef OVERCLOCK_KHZ
  set_sys_clock_khz( OVERCLOCK_KHZ, 1 );
#endif

  /*
   * Set up Pico's Z80 reset pin, hold this at 0 to let Z80 run.
   * Set and hold 1 here to hold Spectrum in reset at startup until we're good
   * to provide its ROM
   */
  gpio_init( PICO_RESET_Z80_GP );  gpio_set_dir( PICO_RESET_Z80_GP, GPIO_OUT );
  gpio_put( PICO_RESET_Z80_GP, 1 );

  /* Create address indirection table, this is the address bus optimisation  */
  create_indirection_table();

  /* Switch the bits in the ROM bytes around, this is the data bus optimisation */
  preconvert_rom( __ROMs_48_original_rom, 16384 );

  /* Pull the buses to zeroes */
  gpio_init( A0_GP  ); gpio_set_dir( A0_GP,  GPIO_IN );  gpio_pull_down( A0_GP  );
  gpio_init( A1_GP  ); gpio_set_dir( A1_GP,  GPIO_IN );  gpio_pull_down( A1_GP  );
  gpio_init( A2_GP  ); gpio_set_dir( A2_GP,  GPIO_IN );  gpio_pull_down( A2_GP  );
  gpio_init( A3_GP  ); gpio_set_dir( A3_GP,  GPIO_IN );  gpio_pull_down( A3_GP  );
  gpio_init( A4_GP  ); gpio_set_dir( A4_GP,  GPIO_IN );  gpio_pull_down( A4_GP  );
  gpio_init( A5_GP  ); gpio_set_dir( A5_GP,  GPIO_IN );  gpio_pull_down( A5_GP  );
  gpio_init( A6_GP  ); gpio_set_dir( A6_GP,  GPIO_IN );  gpio_pull_down( A6_GP  );
  gpio_init( A7_GP  ); gpio_set_dir( A7_GP,  GPIO_IN );  gpio_pull_down( A7_GP  );
  gpio_init( A8_GP  ); gpio_set_dir( A8_GP,  GPIO_IN );  gpio_pull_down( A8_GP  );
  gpio_init( A9_GP  ); gpio_set_dir( A9_GP,  GPIO_IN );  gpio_pull_down( A9_GP  );
  gpio_init( A10_GP ); gpio_set_dir( A10_GP, GPIO_IN );  gpio_pull_down( A10_GP );
  gpio_init( A11_GP ); gpio_set_dir( A11_GP, GPIO_IN );  gpio_pull_down( A11_GP );
  gpio_init( A12_GP ); gpio_set_dir( A12_GP, GPIO_IN );  gpio_pull_down( A12_GP );
  gpio_init( A13_GP ); gpio_set_dir( A13_GP, GPIO_IN );  gpio_pull_down( A13_GP );

  gpio_init( D0_GP  ); gpio_set_dir( D0_GP,  GPIO_OUT ); gpio_put( D0_GP, 0 );
  gpio_init( D1_GP  ); gpio_set_dir( D1_GP,  GPIO_OUT ); gpio_put( D1_GP, 0 );
  gpio_init( D2_GP  ); gpio_set_dir( D2_GP,  GPIO_OUT ); gpio_put( D2_GP, 0 );
  gpio_init( D3_GP  ); gpio_set_dir( D3_GP,  GPIO_OUT ); gpio_put( D3_GP, 0 );
  gpio_init( D4_GP  ); gpio_set_dir( D4_GP,  GPIO_OUT ); gpio_put( D4_GP, 0 );
  gpio_init( D5_GP  ); gpio_set_dir( D5_GP,  GPIO_OUT ); gpio_put( D5_GP, 0 );
  gpio_init( D6_GP  ); gpio_set_dir( D6_GP,  GPIO_OUT ); gpio_put( D6_GP, 0 );
  gpio_init( D7_GP  ); gpio_set_dir( D7_GP,  GPIO_OUT ); gpio_put( D7_GP, 0 );

  /* Input from logic hardware, indicates the ROM is being accessed by the Z80 */
  gpio_init( ROM_ACCESS_GP ); gpio_set_dir( ROM_ACCESS_GP, GPIO_IN );
  gpio_pull_down( ROM_ACCESS_GP );

  /* Blip LED to show we're running */
  gpio_init(LED_PIN);  gpio_set_dir(LED_PIN, GPIO_OUT);

#define FLASH_LED_WHEN_RUNNING 0
#if FLASH_LED_WHEN_RUNNING
  int signal;
  for( signal=0; signal<2; signal++ )
  {
    gpio_put(LED_PIN, 1);
    busy_wait_us_32(250000);
    gpio_put(LED_PIN, 0);
    busy_wait_us_32(250000);
  }
#endif

  gpio_put(LED_PIN, 0);

  /* Stuff other than the ROM emulation happens on the other core */
  multicore_launch_core1( core1_main ); 

  /* All interrupts off, the ROM emulation on this core needs to run uninterrupted */
  irq_set_mask_enabled( 0xFFFFFFFF, 0 );

  while(1)
  {
    register uint32_t gpios_state;

    /*
     * Spin while the hardware is saying at least one of A14, A15 and MREQ is 1.
     * ROM_ACCESS is active low - if it's 1 then the ROM is not being accessed.
     * Also break out when the user button is pressed.
     */
    while( (gpios_state=gpio_get_all()) & ROM_ACCESS_BIT_MASK );

    register uint16_t raw_bit_pattern = pack_address_gpios( gpios_state );

    register uint16_t rom_address = address_indirection_table[raw_bit_pattern];

    register uint8_t rom_value = *(rom_image_ptr+rom_address);

    /* The level shifter is enabled via hardware, so just set the GPIOs */
    gpio_put_masked( DBUS_MASK, rom_value );

    /*
     * Spin until the Z80 releases MREQ indicating the read is complete.
     * ROM_ACCESS is active low - if it's 0 then the ROM is still being accessed.
     */
    while( (gpio_get_all() & ROM_ACCESS_BIT_MASK) == 0 );


    /*
     * Just leave the value there. The level shifter gets turned off by hardware
     * which means the value will disappear from the Z80's view when the Z80's
     * read is complete. At which point the GPIO's state doesn't matter.
     */

  } /* Infinite loop */

}



#if 0
/* Blip the result pin, shows on scope */
gpio_put( TEST_OUTPUT_GP, 1 ); busy_wait_us_32(5);
gpio_put( TEST_OUTPUT_GP, 0 ); busy_wait_us_32(5);

gpio_put( TEST_OUTPUT_GP, 1 ); busy_wait_us_32(1000);
gpio_put( TEST_OUTPUT_GP, 0 ); busy_wait_us_32(1000);
__asm volatile ("nop");
#endif

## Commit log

2023-01-01 fix error on pico input, it needs to know about any access, not just reads
    [srom.kicad_sch]
2023-01-03 first effort at a layout
    [srom.kicad_pcb, srom.kicad_sch]
2023-01-03 minor updates to layout
    [srom.kicad_pcb]
2023-01-03 fab1.0 ready to go
    [srom-B_Cu.gbl, srom-B_Mask.gbs, srom-B_Paste.gbp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]
2023-01-18 fix a couple of footprint errors with v1.0
    [srom.kicad_sch]
2023-01-19 start on firmware, timings look ok with overclock, not working though
    [zx_pico_rom_fw.c]
2023-01-20 try the address value optimisation, doesn't work, probably too complex to bother with. i'll take it out again
    [zx_pico_rom_fw.c]
2023-01-24 hardware mod to add reset feature
    [srom.kicad_sch]
2023-01-24 tidy up, trying to work out the issue i've introduced
    [zx_pico_rom_fw.c]
2023-01-27 periodic z80 reset test code, needs to come out but worth keeping
    [zx_pico_rom_fw.c]
2023-01-28 reset button working, first version
2023-01-28 preconvert all rom images; rom switch button almost working
2023-01-28 rom switching appears to work
2023-01-28 rom switching now working
2023-01-29 finalise v1.1 schematic
    [srom.kicad_sch]
2023-01-29 update pcb with errata
    [srom.kicad_pcb]
2023-01-29 add a ground plane on the back
    [srom.kicad_pcb]
2023-01-30 fab1.1 off for fabrication
    [srom-B_Cu.gbl, srom-B_Mask.gbs, srom-B_Paste.gbp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]
2023-01-31 switcher ROM starts
2023-01-31 oops, remove switcher compiler junk properly
2023-01-31 basic rom switcher working
2023-01-31 clean up rom switcher, but i've gone wrong, need to back this out
    [zx_pico_rom_fw.c]
2023-01-31 switcher rom appears correct now
    [zx_pico_rom_fw.c]
2023-02-06 Add the /M1 line into the Pico so the IF1 ROM can be used
    [srom.kicad_pcb, srom.kicad_sch]
2023-02-06 Tidy IF1 ROM switching, works intermittently given there's no /M1 signal
2023-02-15 v1.2 schematic and layout complete
    [srom.kicad_pcb, srom.kicad_sch]
2023-02-16 there's a race in switcher code, tidy up with alarms, better but i think it's still there
2023-02-16 prepare v1.2, bit more to do yet
    [srom.kicad_pcb]
2023-02-22 add BOM to README
2024-08-01 add v1.2 gerbers
    [srom-B_Cu.gbl, srom-B_Mask.gbs, srom-B_Paste.gbp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]
2024-12-14 create v1.3 pcb with switch casing grounded, circuit is unchanged. kicad v8 automatic update at this point
    [srom.kicad_pcb]
2024-12-14 fix ROM NMI bug. fix button debounce
    [zx_pico_rom_fw.c]
2025-01-27 pio timing loop appears to be correct now
    [zx_pico_nmi_lower_border.c]
2025-01-30 update lower border test, hardware issues resolved, picking this up again
    [zx_pico_nmi_lower_border.c]
2025-02-06 tidy up timers, start NMI at ZX boot time, glitching seems to have gone
    [zx_pico_nmi_lower_border.c]

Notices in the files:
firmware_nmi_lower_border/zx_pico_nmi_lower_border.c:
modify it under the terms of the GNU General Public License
